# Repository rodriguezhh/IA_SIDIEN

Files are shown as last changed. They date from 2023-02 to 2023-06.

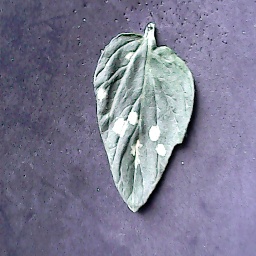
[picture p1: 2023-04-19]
Software/Interfaz/pruebas_de_rendimiento/parejas_early/parejas_early/2023-04-05 05_23_51.373162.JPG

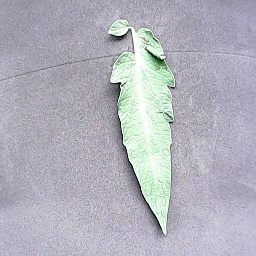
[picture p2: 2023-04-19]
Software/Interfaz/pruebas_de_rendimiento/parejas_healthy/parejas_healthy/2023-03-28 23_35_18.560721.JPG

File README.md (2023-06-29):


# DIAGNÓSTICO DE ENFERMEDADES EN LA HOJA DEL TOMATE MEDIANTE UN SISTEMA EMBEBIDO USANDO INTELIGENCIA ARTIFICIAL E IMÁGENES.

## Descripción del sistema

Este proyecto tiene como objetivo diseñar e implementar un algoritmo de aprendizaje profundo que permita identificar enfermedades en la hoja de la planta del tomate desplegado en un sistema embebido. El sistema está destinado para servir como herramient a agricultores experimentados como a ingenieros agrónomos, con el objetivo de realizar diagnósticos tempranos y asegurar la salud del cultivo.Además, la implementación de este sistema también puede tener fines educativos, permitiendo el estudio de las enfermedades que afectan a las hojas de tomate y apoyando el seguimiento de los cultivos.

Para llevar a cabo este proyecto, se utilizó una base de datos proporcionada por la comunidad Kaggle. Además, se visitaron diferentes invernaderos para capturar imágenes de hojas sanas y enfermas de los cultivos de tomate. Se emplearon herramientas de software libre y código abierto para cada etapa del proyecto.

Se entrenó una inteligencia artificial de jerarquía simplificada y tres modelos de Transfer Learning utilizando Google Colaboratory.

Finalmente, el modelo resultante fue implementado en dos sistemas embebidos, NVIDIA Jetson Nano de 4GB y Raspberry pi 4B. Se realizó un análisis comparativo de los resultados obtenidos para validar su rendimiento en ambas tarjetas de desarrollo.

## Video sobre el desarrollo del proyecto.
https://youtu.be/ES93pp3hpe4

## Drive del proyecto.
https://drive.google.com/drive/folders/18Io3CUIHZYFtg3d0LMKD3wjqCA_87UzG?usp=sharing

## Manual de Usuario 
### Paso a paso del Hardware
1. Accione el interruptor para encender el dispositivo TOLD2.

2. Si va a hacer uso del porta muestras, accione el interruptor para encender la luz del dispositivo TOLD2.

3. Seleccione la muestra de hoja de la plante del tomate que desea inspeccionar y asegurela con el alfiler en el porta muestras y depositela.

<p align="center">
  
</p>

5. Diríjase al apartado ’Paso a paso de la interfaz de usuario’ para proceder con el diagnóstico.

 ### NOTA: 
 En caso de que el dispositivo TOLD2 no encienda, conecte el cargador en el puerto al costado del dispositivo TOLD2. 

### Paso a paso de la Interfaz de usuario 
1. Al iniciar el dispositivo, debe observar la siguiente pantalla.

2. Haga doble click sobre el icono "hacer detección". Acontinuación se debe abrir una interfaz como la siguiente. Asegurese de abrir el software unicamente con dos clicks, de lo contrario se abrirá más de una ventana.

3. Captue la imagen haciendo click en el boton "Tomar foto". 
4. Haga click en el botón "hacer detección". 
5. Finalemte podra observar un diagnóstico de su hoja, además. Si desea realizar otra predicción puede hacer click sobre ”Nueva detección" y repita el proceso cuantas veces desee.



## Contribución
Este proyecto se encuentra en constante evolución, por lo que cualquier contribución será bienvenida. Si deseas contribuir, por favor envía un pull request o contacta al equipo de desarrollo.

## Contacto 
* Camilo Andres Santos Ortiz. camilosantos6584@gmail.com
* Harold Hernando Rodriguez Rodriguez. rodriguezhh03@gmail.com
* Wilmer Andres Guerrero Rangel. andresguerrero1204@gmail.com

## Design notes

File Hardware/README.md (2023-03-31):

# Contenido
Dentro de la carpeta actual, se encuentran todos los archivos relacionados con el hardware utilizados en el proyecto.

## FreeCAD
En la carpeta FreeCAD, se enceuntran los archivos que corresponeden a las tres diferentes versiones del encapsulado, desarrolladas durante el proceso del proyecto. Estos archivos son una base para los siguiente desarrollos. 

## PCB_LED
La carpeta PCB_led contiene los archivos relacionados con el diseño de la PCB del circuito que proporciona la iluminacion del dispositivo. Este diseño nos permite realizar la toma de las imagenes con un ambiente controlado. 

## Planos
En la carpeta Planos, se pueden visualizar las dimensiones exactas de cada una de las piezas diseñadas, siendo estas presentadas en planos separados con el objetivo de facilitar su interpretacion. 

## STL
En cuanto a la carpeta STL, se encuentran ubicados los archivos utilizados para la impresion 3D del encapsulado. Se recomienda tener en cuenta que la impresión se realizo con el material PLA de 0.75 mm. 

## SVG
En la carpeta SVG, se encuentran los archivos de corte laser de las piezas que nos proporcionan bases dentro del encapusaldo para organizar los dispositivos, además, se encuentra el archivo del porta muestras el cual facilita la toma de datos. Los cortes se realizaron con un acrílico transparente de 3 mm de grosor. 

# Como se usa
1. Dirijase a la carpeta STL,  descargue todos los archivos y envielos a impresión 3D.
2. Dirijase a la carpeta SVG,  descargue todos los archivos y envielos a corte laser. 
3. Dirijase a la carptea PCB_LED, descargue los planos de impresión .PDF y fabrique su PCB.
4. Finalmente realice el proceso de ensamblado.

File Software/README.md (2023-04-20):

# Contenido
Dentro de esta carpeta, se encuentran todos los archivos relacionados con el procesamiento de los datos del proyecto.

## Base de datos
En el siguiente link se encuentra la base de datos:https://drive.google.com/drive/folders/1tE_-uaknxtAyiTTtgUqdADf2sIitAHyi?usp=share_link.

## Inteligencia_Artificial
En la carpeta de Inteligencia_Artificial, Encontramos el algoritmo propuesto de jerarquía reducida, además, de los algoritmos de arqquitecturas de transfer learning, que son VGG19, MobileNetV2 y ResNet50.

## Modelos_IA 
En el siguiente link: https://drive.google.com/drive/folders/1_pJdKnspFUj5AHXt6KV58SqsYDc62IjV?usp=sharing. Se encuentra los .h5 de los diferentes modelos ya entrenados y dispuestos a usar de las distintas arquitecturas de inteligencia artificial. 

## Interfaz
En La carpeta Interfaz contiene los archivos relacionados con el diseño de la PCB del circuito que proporciona la iluminacion del dispositivo. Este diseño nos permite realizar la toma de las imagenes con un ambiente controlado. 

## Procesamiento_de_imagenes
En la carpeta de Procesamiento_de_imagenes, se encuentra el algoritmo de Disivison_datos, con el cual nos permite separar las imagenes en los conjuntos de entrenamiento, validación y prueba, además, se encuentra el algoritmo de Aumento_datos que nos permite generar nuevas imágenes.

*NOTA: para la instalación del software se recomienda utilizar como mínimo una tarjeta SD de 32GB.
# Librerias y dependencias para Jetson nano 4GB.
* Imagen de la tarjeta SD: https://github.com/Qengineering/Jetson-Nano-image.git
* PyQt5 5.10.1

# Librerias y dependencias para Rasbpberry pi 4B 4GB.
* Imagen de la tarjeta SD: 
* PyQt5 5.15.2
* opencv 4.7.0.68
* Tensorflow 2.12

# Como se usa
## Creando un modelo 
1. Dirijase a la carpeta de Dataset y descarguela
2. Dirijase a la carpeta de Procesamiento_de_imagenes, descargue el archivo División_datos.py y ejecutelo.
3. Dirijase a la carpeta de Procesamiento_de_imagenes, descargue el archivo Aumento_datos.py y ejecutelo en la carpeta de entrenamiento. 
4. Suba las carpetas a Google Drive.
5. Cree su modelo en Google Colab, puede tomar como base las arquitecturas propuestas en la carpeta Inteligencia_Artificial
6. Entrene su modelo y guardelo para que se pueda desplegar. 

* NOTA: si quiere evitar el proceso de entreanmiento y creación de un modelo. puede descargar alguno de la carpeta Modelos_IA 

## Despliegue en Jetson nano 4GB.
1. Instale la imagen de la Jetson nano en la memoria SD siguiendo los pasos del repositorio de GitHub https://github.com/Qengineering/Jetson-Nano-image.git
2. Instale las dependenciaas requeridas por la Jetson Nano de 4 GB. Unicamente instale PyQt5 ya que en la imagen instalada anteriormente se encuentran la mayoría de librerias necesarias para el funcionamiento del sistema.
3. Una vez instaladas las librerías necesarias, descargue la carpeta https://github.com/rodriguezhh/IA_SIDIEN/tree/main/Software/Interfaz/told2_v0.1. Esta carpeta contiene los archivos y recursos necesarios para el funcionamiento de la interfaz de detección.
4. Descargue el modelo ResNet50 entrenado del siguiente link https://drive.google.com/file/d/1AAf66BFohPHkJcNdAy4Eeix6V2cA7vEN/view?usp=share_link y agreguelo a la carpeta que descargó en el paso anterior.
5. Para ejecutar la interfaz, abra una terminal en la carpeta donde se encuentra em main.py, y ejecute el siguiente comando: `python3 main.py`

## Despliegue en Rasbpberry pi 4B 4GB.
1. Descargue el software Raspberry PI Imager (https://www.raspberrypi.com/software/), asegurese que sea compatible con el sistema operativo de su equipo.
2. Usando Raspberry PI Imager seleccione la imagen correspondiente a la Raspberry PI 4B e instalela en la tarjeta SD.
3. Instale las dependencias requeridas, las cuales son OpenCV, PyQt5 y tensorflow usando el comando `pip install`.
4. Finalmente realice los pasos del 3 al 5, descritos en el Despliegue para Jetson nano 4GB.

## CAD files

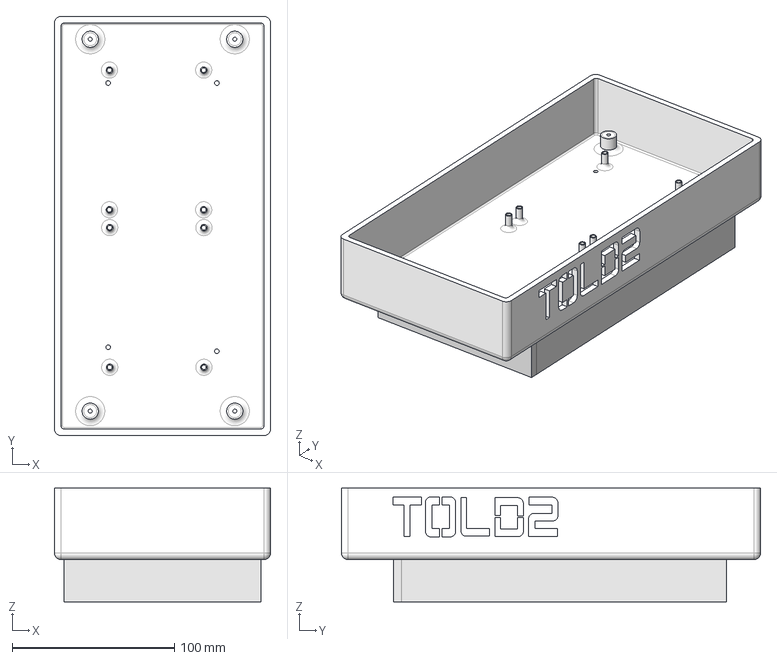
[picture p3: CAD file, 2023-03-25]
Hardware/FreeCAD/Primer_Encapsulado.FCStd
133.0 x 258.0 x 70.0 mm
Fusion- Soporte Camara

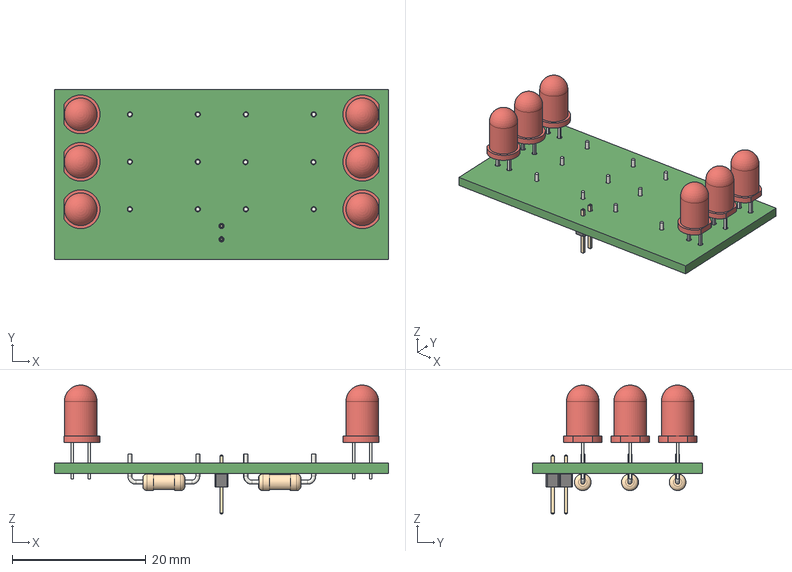
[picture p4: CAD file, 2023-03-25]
Hardware/PCB_leds/pcb_leds.step
50.0 x 25.5 x 19.3 mm

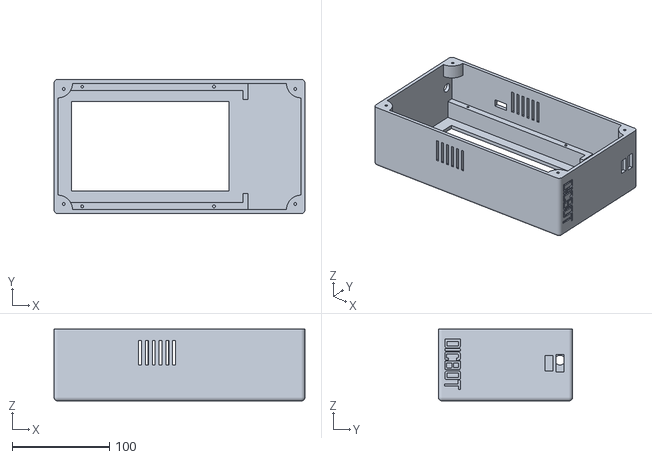
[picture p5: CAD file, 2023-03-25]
Hardware/stl/carcasa_encapsulado.stl
258.0 x 138.0 x 74.0

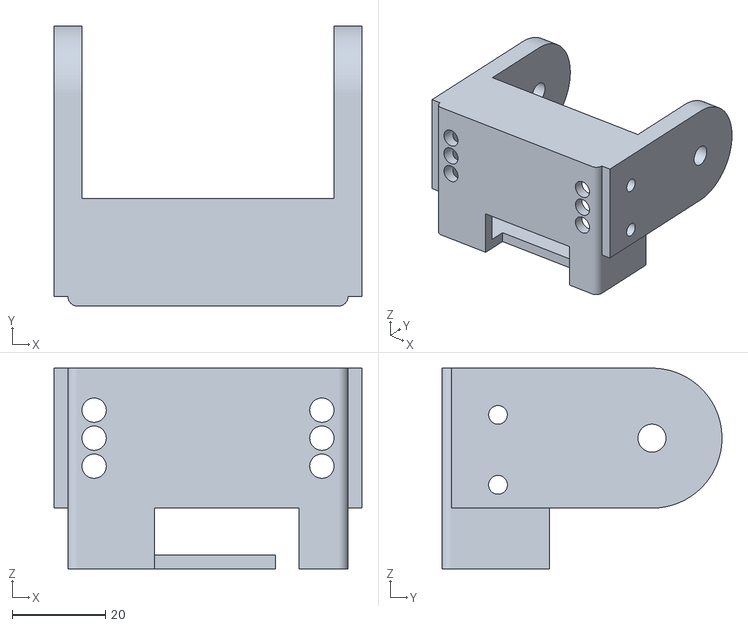
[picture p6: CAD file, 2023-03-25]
Hardware/stl/cabeza_soporte_camara.stl
66.0 x 60.0 x 43.0

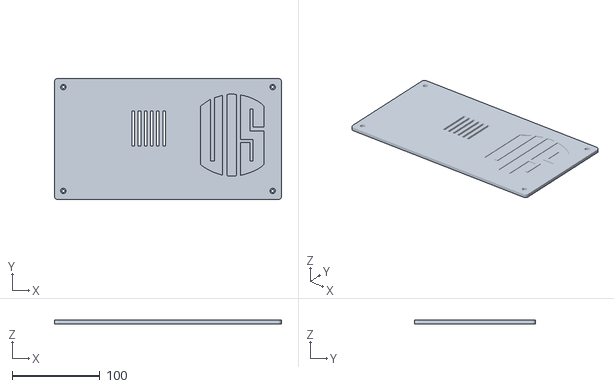
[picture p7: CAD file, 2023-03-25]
Hardware/stl/tapa_encapsulado.stl
258.0 x 138.0 x 4.00

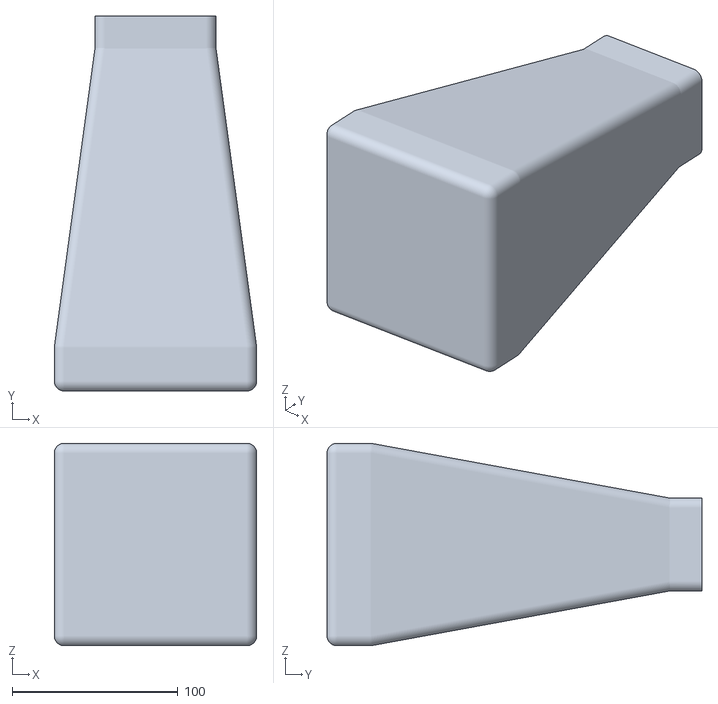
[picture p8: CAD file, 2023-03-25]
Hardware/stl/porta_muestras.stl
122.0 x 226.0 x 122.0

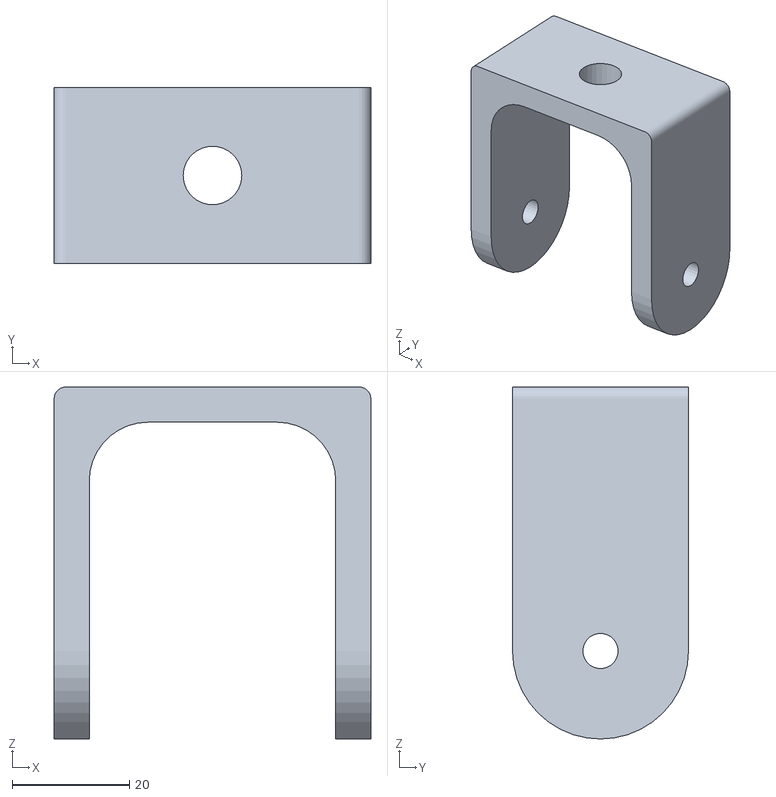
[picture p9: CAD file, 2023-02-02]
Hardware/stl/base_soporte_camara.stl
54.0 x 30.0 x 60.0

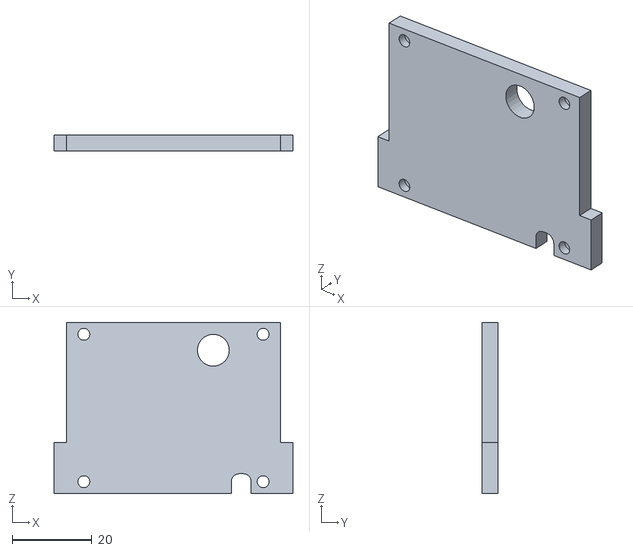
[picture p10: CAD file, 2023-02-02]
Hardware/stl/tapa_soporte_camara.stl
60.0 x 4.00 x 43.0

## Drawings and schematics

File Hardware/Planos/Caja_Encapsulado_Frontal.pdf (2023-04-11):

3

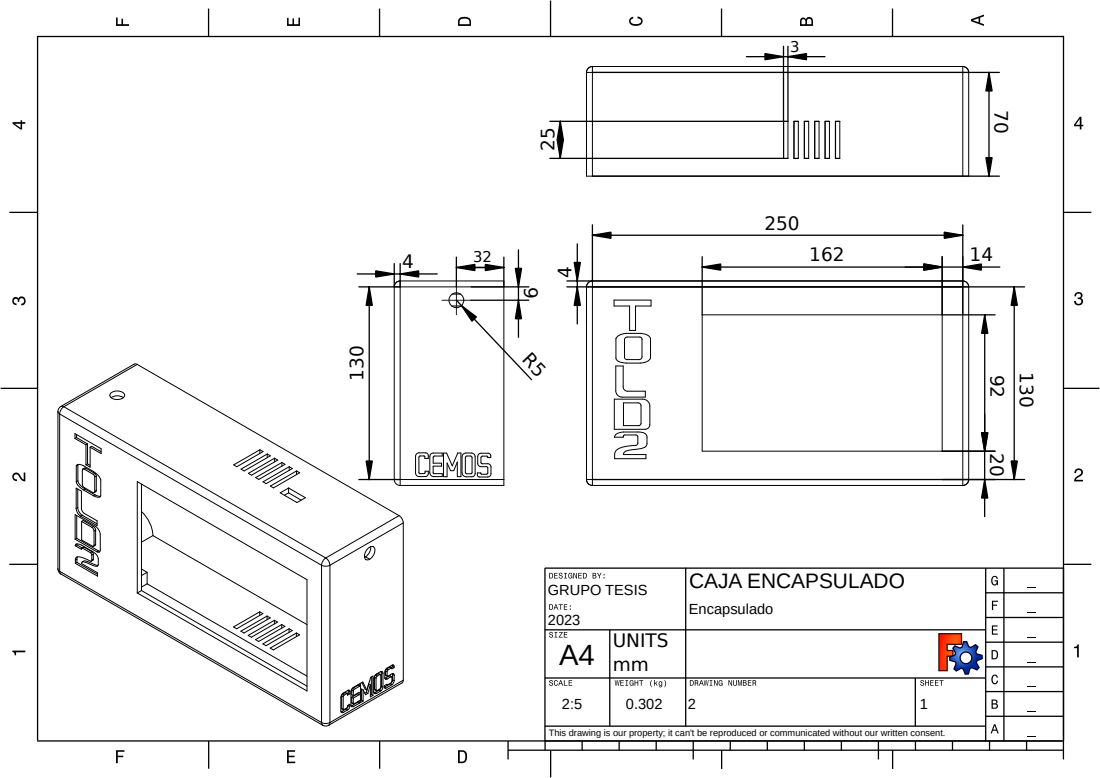
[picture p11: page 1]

GRUPO TESIS 2023 | CAJA ENCAPSULADO Encapsulado
A4 | UNITS mm

This drawing is our property; it can't be reproduced or communicated without our written consent.

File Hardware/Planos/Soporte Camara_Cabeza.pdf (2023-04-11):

16,5 | 31 | 8,5
26 | 5

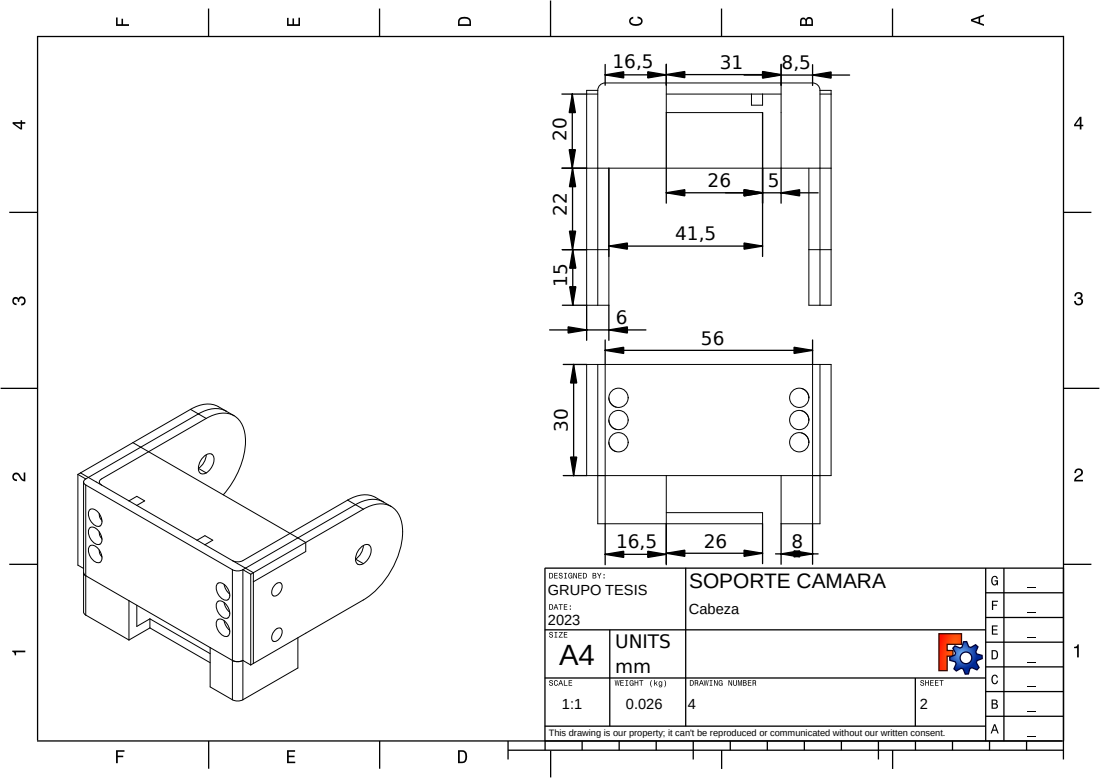
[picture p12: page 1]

GRUPO TESIS 2023 | SOPORTE CAMARA Cabeza
A4 | UNITS mm

This drawing is our property; it can't be reproduced or communicated without our written consent.

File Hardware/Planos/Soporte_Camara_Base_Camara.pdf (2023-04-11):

54

2 | 27

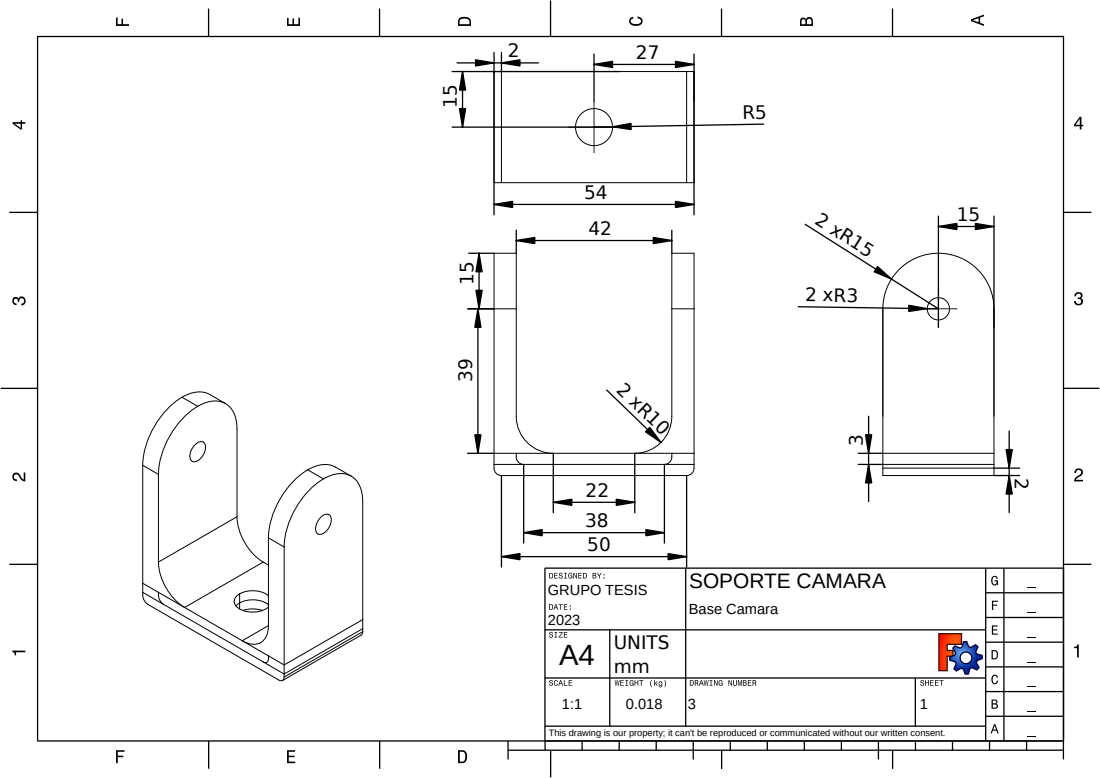
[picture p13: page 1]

GRUPO TESIS 2023 | SOPORTE CAMARA Base Camara

A4 | UNITS mm

This drawing is our property; it can't be reproduced or communicated without our written consent.

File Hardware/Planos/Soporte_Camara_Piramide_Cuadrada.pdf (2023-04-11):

110

180

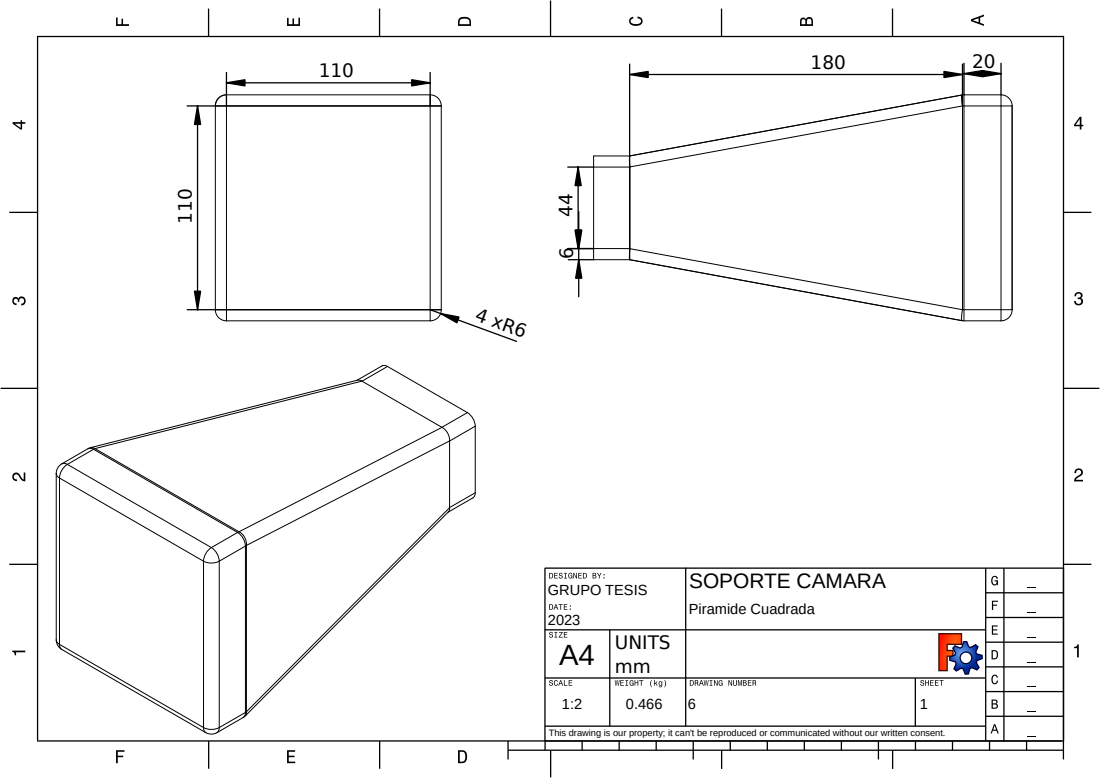
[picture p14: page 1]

GRUPO TESIS 2023 | SOPORTE CAMARA Piramide Cuadrada

A4 | UNITS mm

This drawing is our property; it can't be reproduced or communicated without our written consent.

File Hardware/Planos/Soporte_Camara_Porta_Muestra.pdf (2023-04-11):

4,5 | 60

16

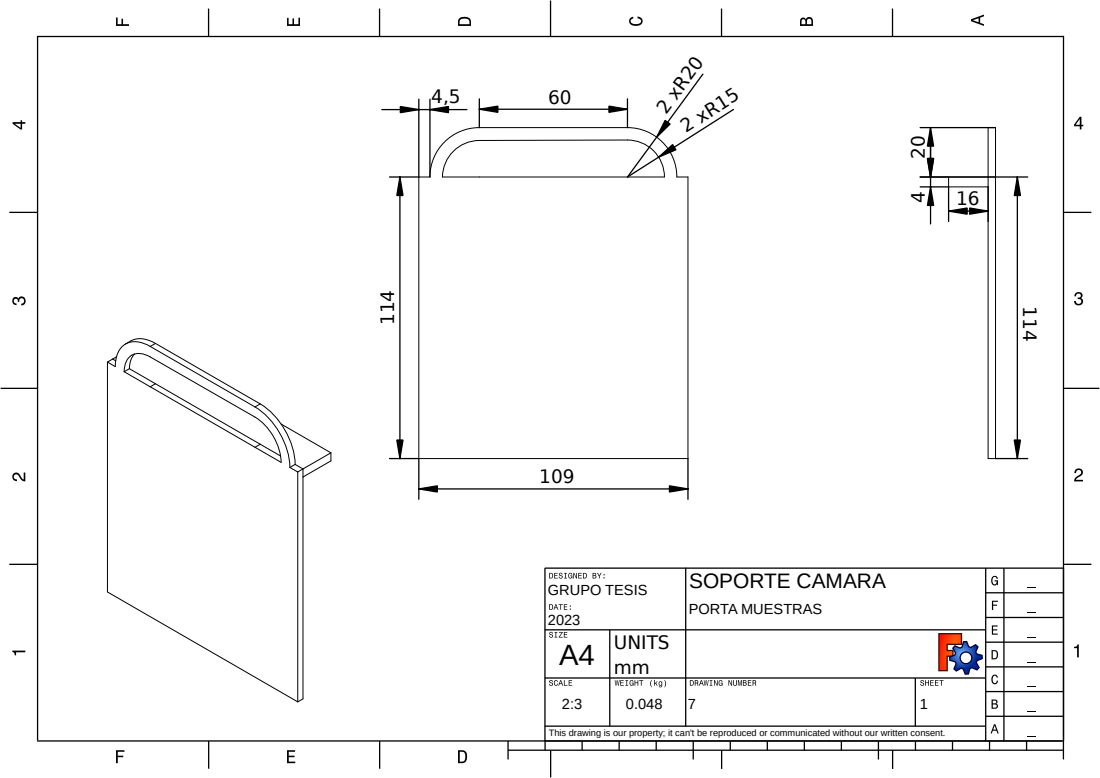
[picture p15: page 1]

GRUPO TESIS 2023 | SOPORTE CAMARA PORTA MUESTRAS

A4 | UNITS mm

This drawing is our property; it can't be reproduced or communicated without our written consent.

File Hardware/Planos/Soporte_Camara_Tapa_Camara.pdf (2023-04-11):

3

17 | 4

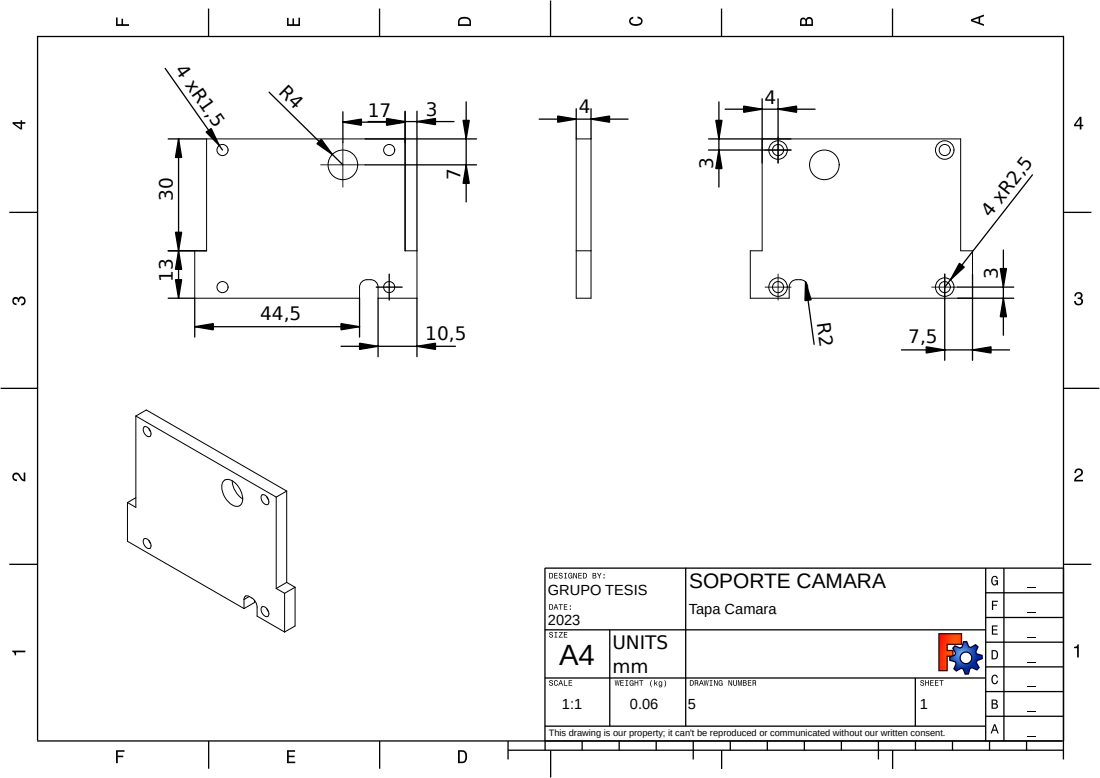
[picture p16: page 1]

GRUPO TESIS 2023 | SOPORTE CAMARA Tapa Camara

A4 | UNITS mm

This drawing is our property; it can't be reproduced or communicated without our written consent.

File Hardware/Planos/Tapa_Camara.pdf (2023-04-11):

3

88

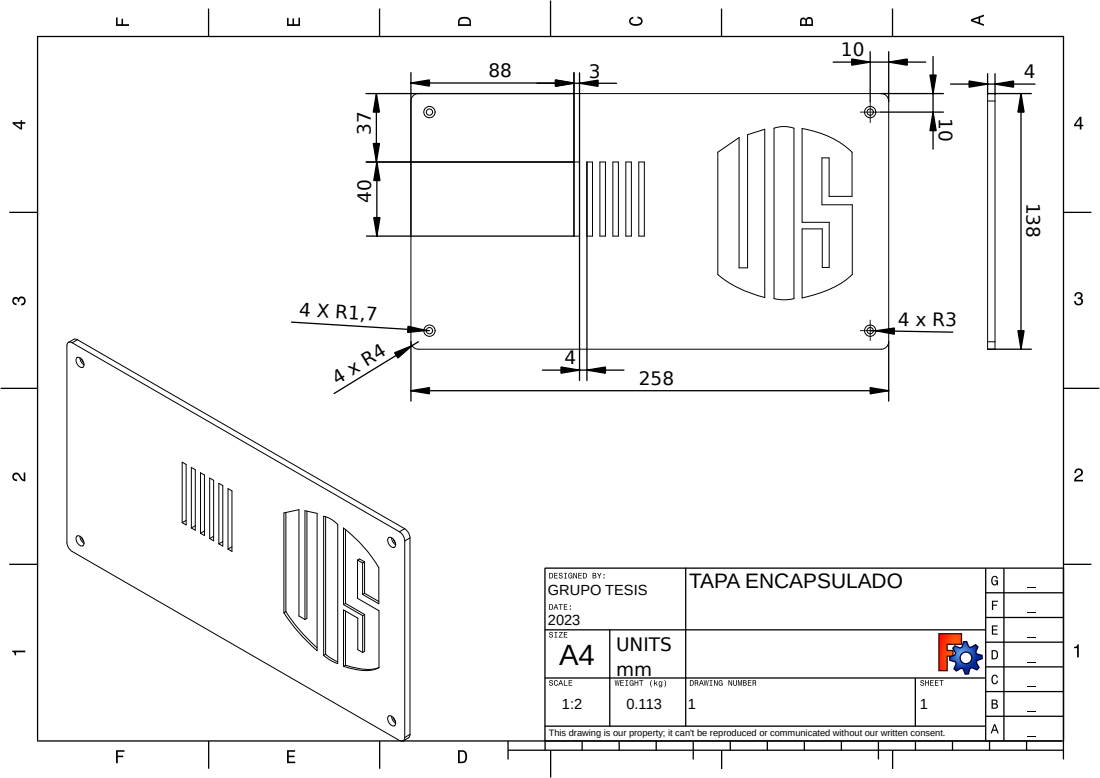
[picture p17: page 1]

GRUPO TESIS 2023 | TAPA ENCAPSULADO

A4 | UNITS mm

This drawing is our property; it can't be reproduced or communicated without our written consent.

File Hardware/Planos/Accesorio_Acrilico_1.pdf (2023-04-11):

3

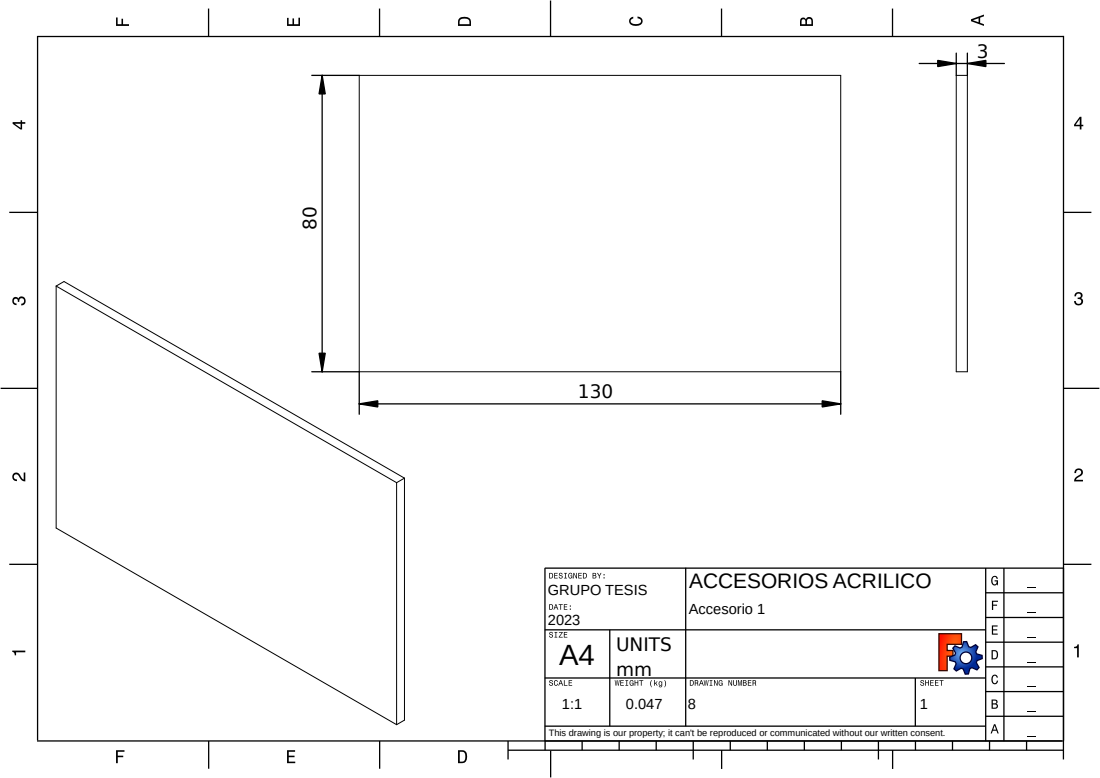
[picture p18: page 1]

GRUPO TESIS 2023 | ACCESORIOS ACRILICO Accesorio 1

A4 | UNITS mm

This drawing is our property; it can't be reproduced or communicated without our written consent.

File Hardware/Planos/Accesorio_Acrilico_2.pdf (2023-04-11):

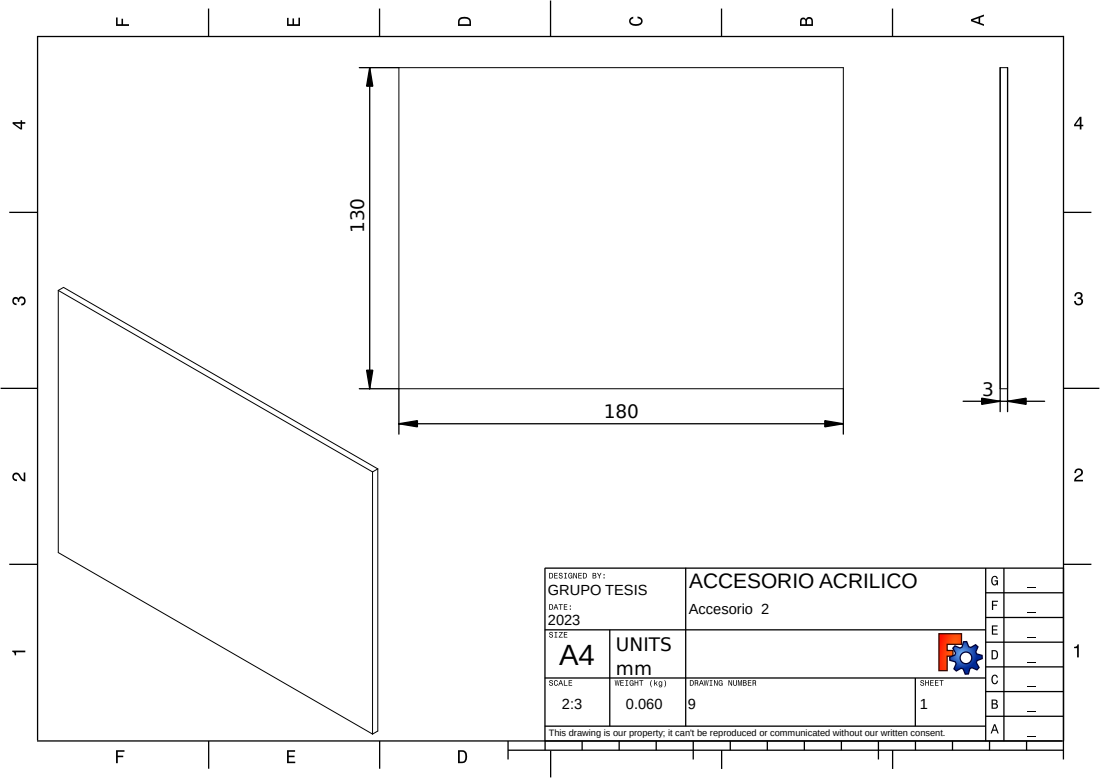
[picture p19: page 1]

GRUPO TESIS 2023 | ACCESORIO ACRILICO Accesorio 2

A4 | UNITS mm

This drawing is our property; it can't be reproduced or communicated without our written consent.

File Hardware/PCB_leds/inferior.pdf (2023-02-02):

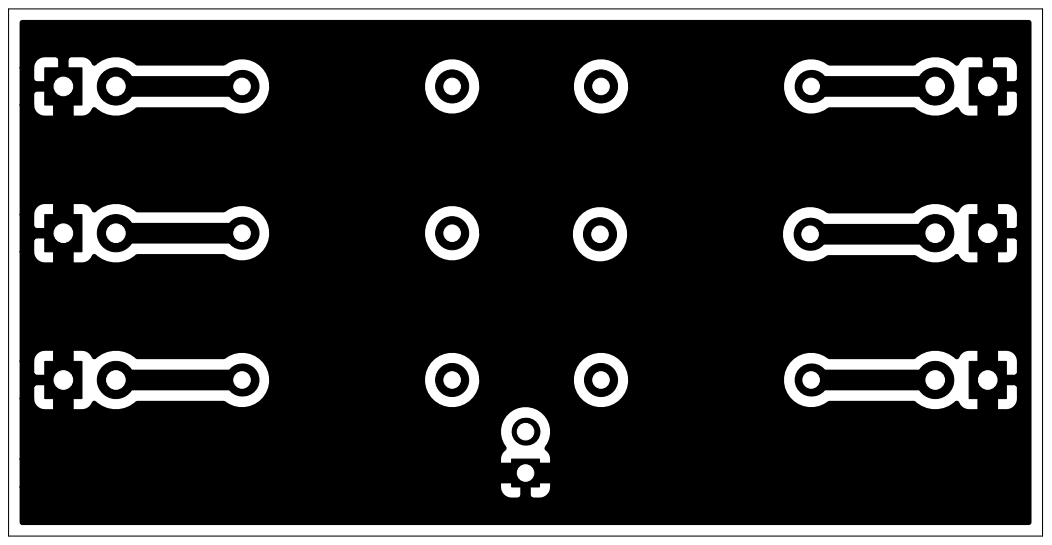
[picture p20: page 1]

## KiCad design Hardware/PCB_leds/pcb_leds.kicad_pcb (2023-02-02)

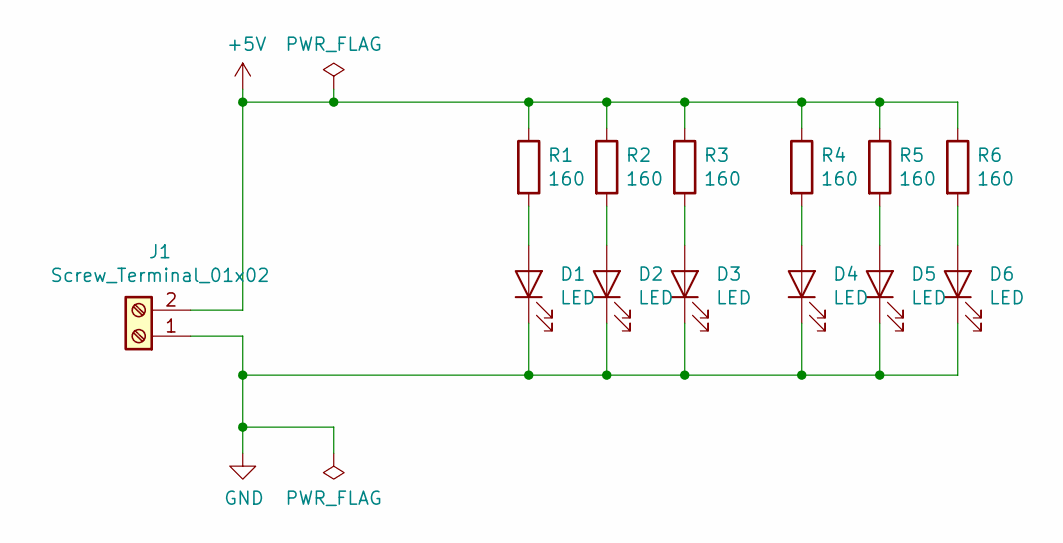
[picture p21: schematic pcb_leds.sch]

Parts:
D1, D2, D3, D4, D5, D6: LED; LED_D5.0mm
J1: Screw_Terminal_01x02; PinHeader_1x02_P2.00mm_Vertical
R1, R2, R3, R4, R5, R6: 160; R_Axial_DIN0207_L6.3mm_D2.5mm_P10.16mm_Horizontal

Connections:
+5V: J1.2, R1.1, R2.1, R3.1, R4.1, R5.1, R6.1
GND: D1.1 (K), D2.1 (K), D3.1 (K), D4.1 (K), D5.1 (K), D6.1 (K), J1.1
unnamed: D1.2 (A), R1.2
unnamed: D2.2 (A), R2.2
unnamed: D3.2 (A), R3.2
unnamed: D4.2 (A), R4.2
unnamed: D5.2 (A), R5.2
unnamed: D6.2 (A), R6.2

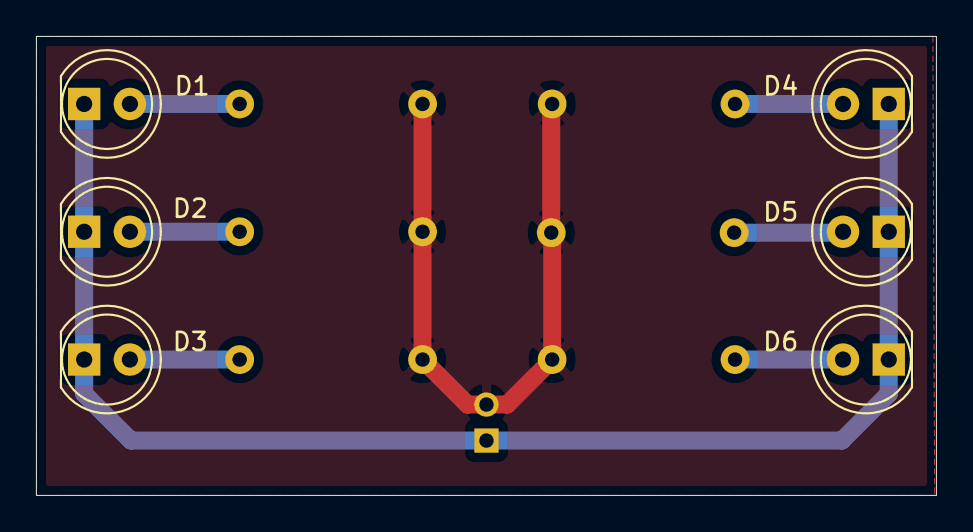
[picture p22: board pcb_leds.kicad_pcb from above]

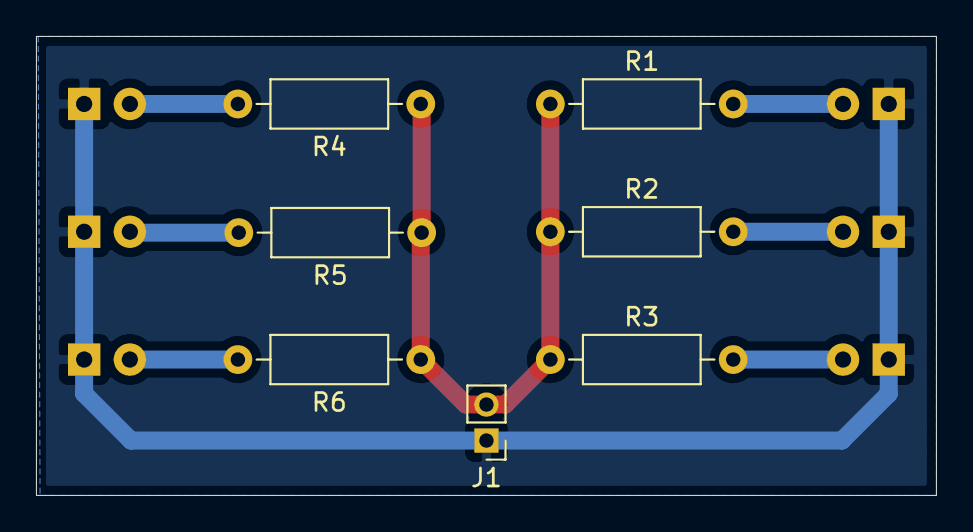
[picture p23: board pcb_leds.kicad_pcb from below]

Board: 2 copper layers, 50.0 x 25.5 mm, 13 parts (7 on the bottom side), 8 nets.

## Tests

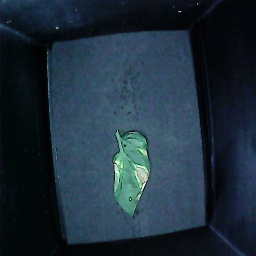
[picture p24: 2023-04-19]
Software/Interfaz/pruebas_de_rendimiento/parejas_late/parejas_late/2023-03-29 00_23_14.581021.JPG

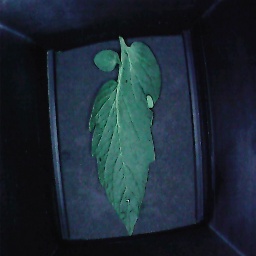
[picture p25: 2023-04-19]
Software/Interfaz/pruebas_de_rendimiento/parejas_healthy/parejas_healthy/2023-03-28 23_35_41.235230.JPG

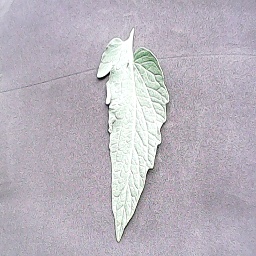
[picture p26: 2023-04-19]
Software/Interfaz/pruebas_de_rendimiento/parejas_healthy/parejas_healthy/2023-03-28 23_36_24.273774.JPG

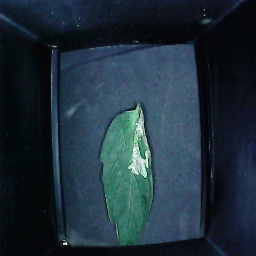
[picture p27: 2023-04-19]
Software/Interfaz/pruebas_de_rendimiento/parejas_early/parejas_early/2023-04-05 05_27_13.663964.JPG

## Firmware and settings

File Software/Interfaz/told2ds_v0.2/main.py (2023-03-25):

import sys
import cv2
from PyQt5.QtWidgets import QApplication, QLabel, QWidget
from PyQt5.QtGui import QIcon, QImage, QPixmap
from PyQt5 import QtWidgets, QtCore
from PyQt5.QtCore import Qt, QThread, pyqtSignal
import numpy as np
import datetime
import os
import GUI
#import Jetson.GPIO as GPIO

# Clase de la interfaz de usuario
class app_VRU(QtWidgets.QMainWindow):
    def __init__(self):
        # Cargar la interfaz de usuario
        super().__init__()
        self.ui = GUI.Ui_MainWindow()
        self.ui.setupUi(self)
        self.setWindowTitle("TOLD2 IA")     # Establecer el título de la ventana principal
        self.start_video()                  # Iniciar la transmisión de video
        self.counter = 0                    # Contador de imágenes guardadas

        # Conectar los botones de la interfaz de usuario a sus funciones correspondientes
        self.ui.save_ph.clicked.connect(self.saveph)
        self.ui.take_ph.clicked.connect(self.takeph)
        self.ui.retake_ph.clicked.connect(self.start_video)
        self.ui.close.clicked.connect(self.salir)

    # Función para actualizar la imagen mostrada en la interfaz de usuario
    def Imageupd_slot(self, Image):
        self.ui.cam.setPixmap(QPixmap.fromImage(Image))

        carpeta = self.ui.cb.currentText() + "/"        # Incrementar el contador de imágenes guardadas
        elementos = os.listdir(carpeta)
        count = len(elementos)
        self.ui.cont.setStyleSheet("color: white;")     # Actualizar el texto de la etiqueta que muestra el número de imágenes guardadas
        self.ui.cont.setText(f"Muestras tomadas: {count}")
    
    # Función para iniciar la transmisión de video
    def start_video(self):

        self.ui.cb.setEnabled(True)
        
        # Ocultar los botones de guardar y volver a tomar la foto
        self.ui.save_ph.hide()
        self.ui.save_ph_tex.hide()
        self.ui.retake_ph.hide()
        self.ui.retake_ph_tex.hide()

        # Mostrar el botón de tomar la foto
        self.ui.take_ph.show()
        self.ui.take_ph_tex.show()

        self.Work = Work()                              # Crear un objeto de trabajo y comenzar su ejecución en un hilo separado
        self.Work.start()                               
        self.Work.Imageupd.connect(self.Imageupd_slot)  # Conectar la señal de actualización de imagen del objeto de trabajo a la función Imageupd_slot de la clase de interfaz

    # Función para tomar una foto
    def takeph(self):

        # Mostrar los botones de guardar y volver a tomar la foto
        self.ui.cb.setEnabled(False)
        self.ui.save_ph.show()
        self.ui.save_ph_tex.show()
        self.ui.retake_ph.show()
        self.ui.retake_ph_tex.show()

        # Ocultar el botón de tomar la foto
        self.ui.take_ph.hide()
        self.ui.take_ph_tex.hide()

        # Detener la transmisión de video estableciendo la variable stop a True
        global stop
        stop = True

    # Función para guardar una foto
    def saveph(self):

        self.ui.cb.setEnabled(False)
        global frame_cache                                             # Redimensionar la imagen guardada a 256x256 píxeles
        frame_cache = cv2.resize(frame_cache, (256, 256))
        dir = self.ui.cb.currentText()
        name_fecha = dir + "/" + str(datetime.datetime.now()) + ".JPG" # Crear un nombre de archivo único basado en la fecha y hora actual
        cv2.imwrite(name_fecha, frame_cache)                           # Guardar la imagen en el disco
        
        self.start_video()                                             # Reiniciar la transmisión de video

    def salir(self):
        sys.exit(app.exec_())

class Work(QThread):
    Imageupd = pyqtSignal(QImage)

    def run(self):
        self.hilo_corriendo = True
        cap = cv2.VideoCapture(0)
        global stop
        stop = False
        while self.hilo_corriendo:
            ret, frame = cap.read()
            Image = cv2.cvtColor(frame, cv2.COLOR_BGR2RGB)
            flip = cv2.flip(Image, 1)
            convertir_QT = QImage(flip.data, flip.shape[1], flip.shape[0], QImage.Format_RGB888)
            pic = convertir_QT.scaled(600, 450, Qt.KeepAspectRatio)
            self.Imageupd.emit(pic)

            if stop:
                global frame_cache
                frame_cache = frame
                #cv2.imwrite("foto.png", frame)
                break

        cap.release()

#Inicio de la interfaz
if __name__=='__main__':
    app = QApplication(sys.argv)
    mainWindow = app_VRU()
    mainWindow.show()
    sys.exit(app.exec_())

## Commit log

2022-12-28 Base inicial para la interfaz, main, gui y archivo qt designer iniciales
2022-12-29 Camara funciona haciendo click en el boton start, aún no se detiene la cámara
2023-01-02 Interfaz funcional para toma de base de datos, permite guardar fotos en una carpeta, nombradas con la fecha y hora del momento
2023-01-08 Se agrega el modelo 3D del cono para el portamuestras junto con el portamuestras
    [SOPORTE_CAMARA.FCStd]
2023-01-20 Cambios con la intefaz para dataset terminada y encapsulado terminado
    [black_box_base.stl, black_box_tapa.stl]
2023-02-02 Se agregan los archivos STL para impresión 3D, los archivos y planos del diseño de la pcb y los archivos svg para corte laser
    [cam_support.FCStd, cono.stl, pcb_leds.kicad_pcb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]
2023-03-25 Organizacion del GIT
    [pcb_leds.kicad_pcb, pcb_leds.sch, pcb_leds.step]
2023-03-25 Remover carpeta de interfaz
2023-03-25 Removiendo PCB
    [pcb_leds.kicad_pcb, pcb_leds.sch]
2023-03-25 Remover stl, svg y agregar carpetas
    [black_box_base.stl, black_box_tapa.stl, cono.stl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]
2023-03-25 removiendo archivos fuera de Software
2023-03-25 Remover archivo FCStd del inicio
    [cam_support.FCStd]
2023-03-25 Creacion de las carpetas necesarias y ordenamiento
2023-03-25 Se agregaron los archivos FCStd y los archivos stl para impresion
    [base_soporte_camara.stl, cabeza_soporte_camara.stl, carcasa_encapsulado.stl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]
2023-04-03 Creación de las carpetas Dataset y Modelos de IA
2023-04-19 Ajuste de nuevas carpetas
2023-04-19 Ajuste carpeta de pruebas in situ
2023-04-19 Ajuste de archivos en las respectivas carpetas
2023-04-20 Cambios en los archivos de interfaz
2023-04-20 Actualización de archivos .svg
